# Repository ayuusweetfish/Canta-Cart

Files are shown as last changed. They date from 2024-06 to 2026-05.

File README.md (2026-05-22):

# Canta-Cart

Canta-Cart is a touch-operated musical instrument/synthesiser that takes the dimensions of a standard ID-1 card (85.6 × 53.98 mm). A portable little tune-maker in the pocket, it is easy for anyone to get hands on, yet versatile enough for the more aspiring of minds. It is plug-and-play — a USB-C power supply will take its sounds anywhere.

Additionally, the total BOM cost of CN¥5 / US$0.7 makes it an ideal greeting giveaway.

🎥 Videos:
- ["Merry Go Round of Life"](https://vimeo.com/989413177)
- ["A Short Hike"](https://vimeo.com/980840986)
- ["Pigeons and a Boy"](https://vimeo.com/970898009)

🕹️ [**Try in the browser**](https://ayuusweetfish.github.io/Canta-Cart/synth/)  
🌟 [Personal wiki page](https://ayu.land/canta)  
⚙️ [Hackaday project page](https://hackaday.io/project/196643-canta-cart)

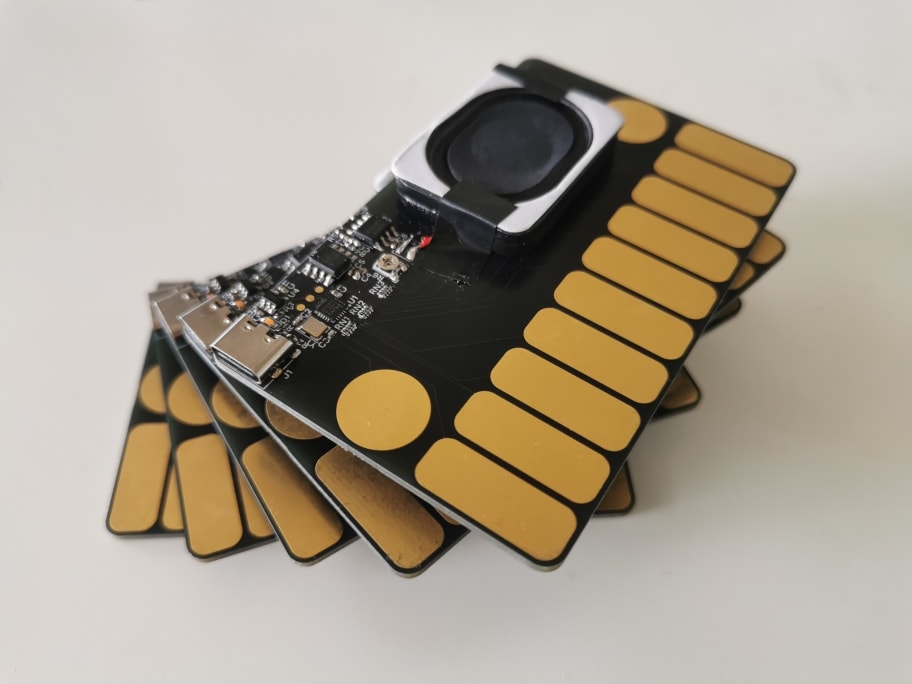
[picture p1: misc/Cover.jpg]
A stack of card-sized electronic devices


## Directory Structure
- **hw/**: Circuit board design in KiCad
- **fw/**: Firmware
  - To build this, you would need a copy of the following files:
    - **debug/Puya.PY32F0xx_DFP.1.2.1.pack**: Support pack used by PyOCD for flashing and debugging. Download from [Arm Keil’s website](https://www.keil.arm.com/packs/py32f0xx_dfp-puya/versions/). (SHA-1: `d3d40536eb2b465c1fbe483f0e1d66b776cbcbb6`)
      - This can also be installed through PyOCD’s pack management system.
    - **PY32F0xx_Firmware_V1.4.1/**: Firmware library. Download from [Puya’s website](https://www.puyasemi.com/en/gongjuyuruanjian.html). (Zip SHA-1: `c5146b8456401b8718d24bd71ab4e5568bd2c0f8`)
  - And the following software (versions for reference):
    - GNU Make (3.81)
    - Arm GNU Toolchain (GCC 10.3.1)
    - PyOCD (0.36.0)
  - Run `make` to build; `make flash` to upload. Add `OPT=-O3` for an optimised build (released version).
- **misc/synth/**: The synthesiser application (emulator) and its WebGL port, both implemented with [Sokol](https://github.com/floooh/sokol)
  - **canta_synth.h**: The actual synthesiser implementation, which is also included from the firmware
- **releases/**: Gerber files submitted to fabrication houses and firmware binaries at pinned revisions

## Licence
All content in this repository is distributed under CERN-OHL-S (CERN Open Hardware Licence Version 2, Strongly Reciprocal). See full text at `COPYING.txt` or [online](https://ohwr.org/cern_ohl_s_v2.txt).

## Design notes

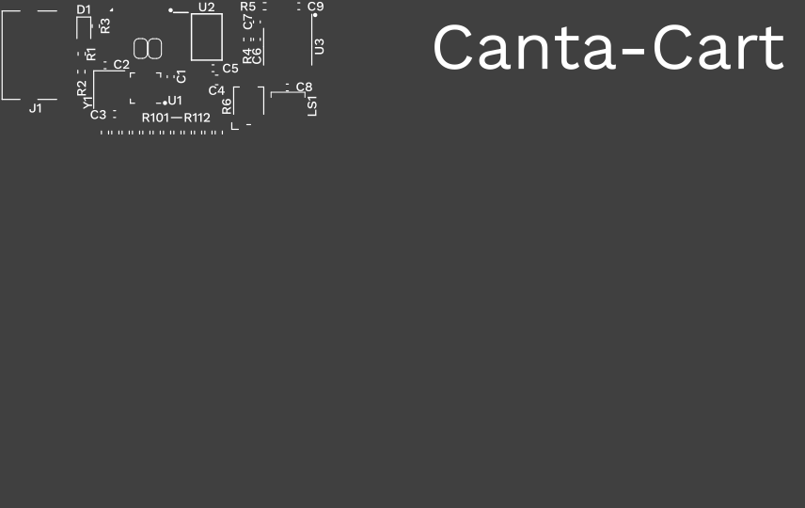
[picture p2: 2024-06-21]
misc/synth/silkscreen.png

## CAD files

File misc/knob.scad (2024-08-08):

$fa = 1.5;  // Facet min. angle (deg)
$fs = 0.05; // Facet min. length

// https://gist.github.com/mildsunrise/327a828e59ed97176ab7dbbaabb4d216
module gear(teeth, step, height=0.2) {
  angle = 360 / (teeth*2);
  radius = (step/2) / sin(angle/2);
  apothem = (step/2) / tan(angle/2);
  
  module circles() {
    for (i = [1:teeth])
      rotate(i*angle*2) translate([radius, 0, 0]) circle(step/2);
  }
  
  linear_extrude(height) difference() {
    union() {
      circle(apothem);
      circles();
    }
    rotate(angle) circles();
  }
}

// cylinder(h = 1.5, r = 3);
gear(24, 0.4, height = 1);

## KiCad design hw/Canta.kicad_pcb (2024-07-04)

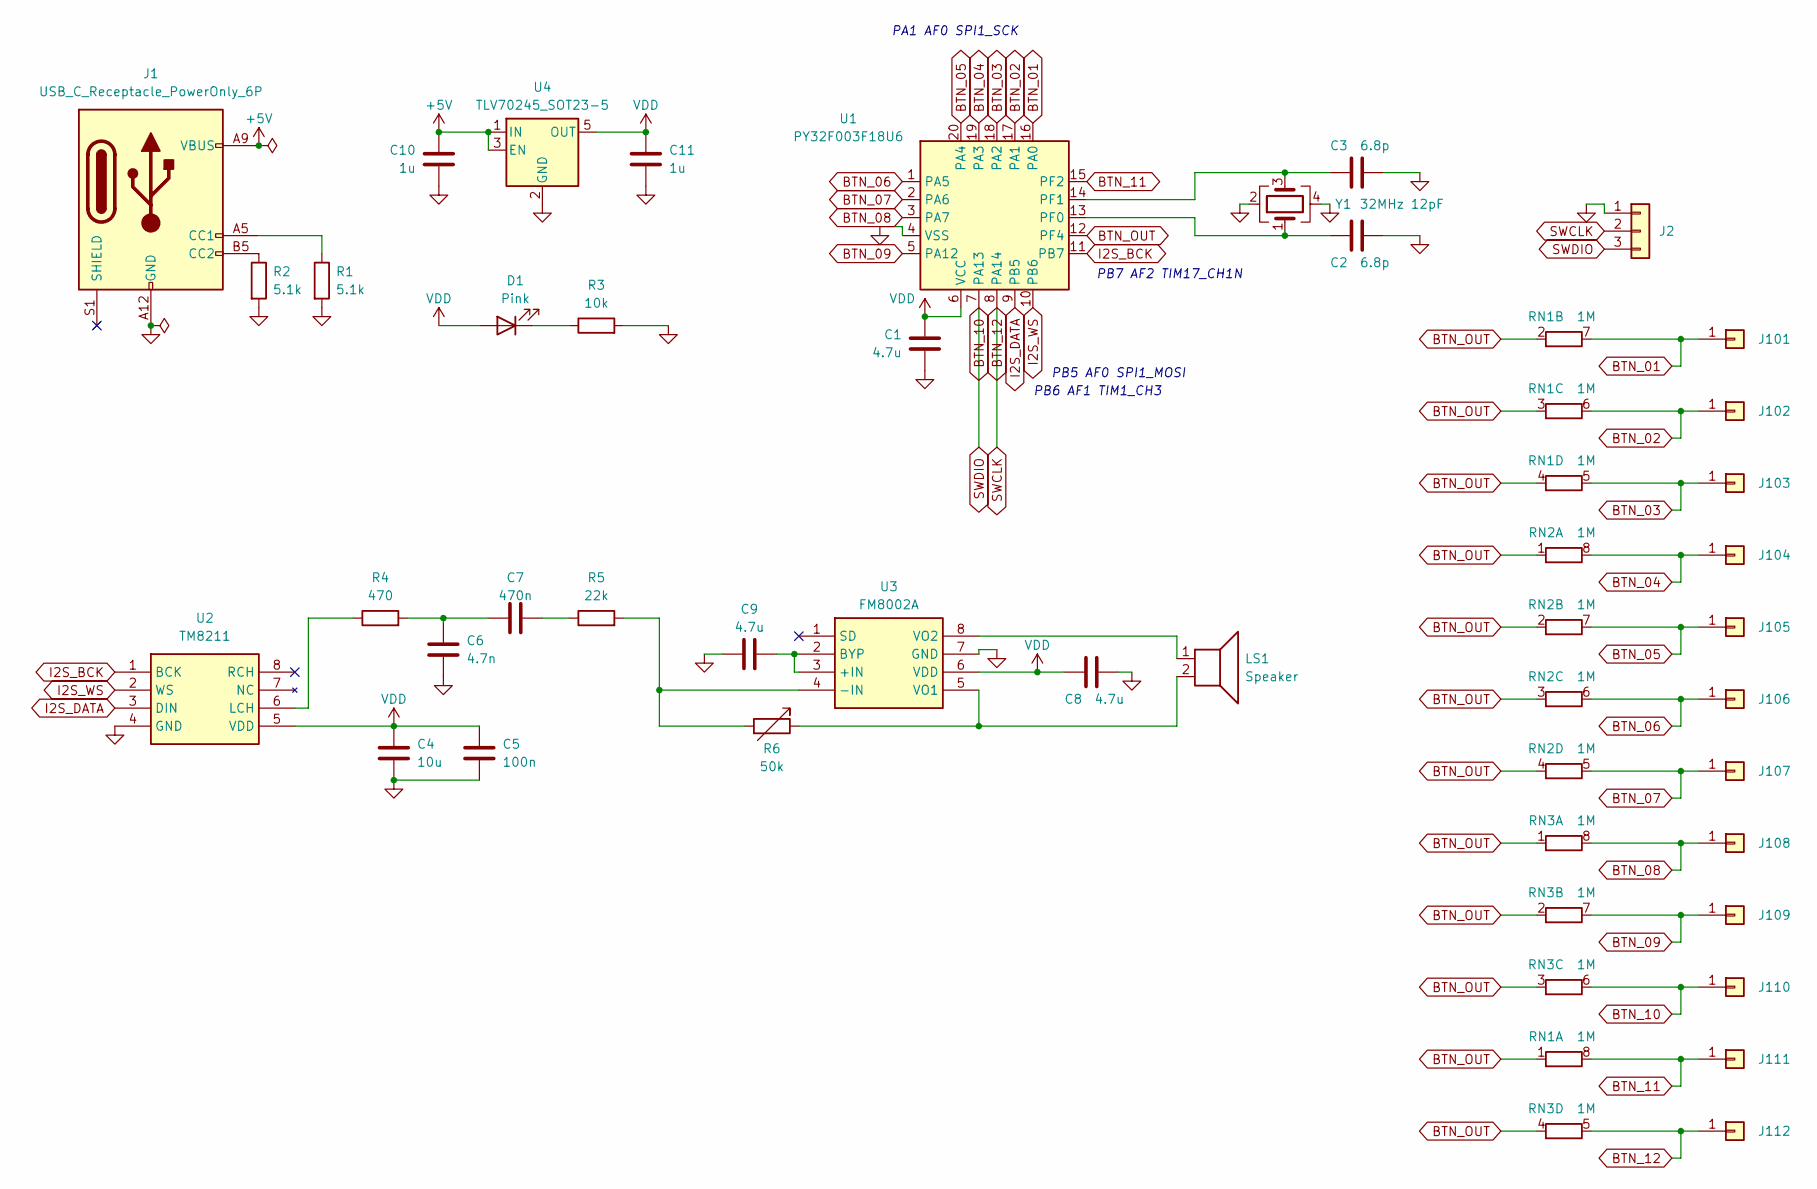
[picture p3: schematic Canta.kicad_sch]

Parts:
C1, C8, C9: 4.7u; C_0402_1005Metric
C2, C3: 6.8p; C_0402_1005Metric
C4: 10u; C_0603_1608Metric
C5: 100n; C_0402_1005Metric
C6: 4.7n; C_0402_1005Metric
C7: 470n; C_0402_1005Metric
C10, C11: 1u; C_0402_1005Metric
D1: Pink; LED_0603_1608Metric
J1: USB_C_Receptacle_PowerOnly_6P; USB_C_Receptacle
J2: Conn_01x03; TestPoints_1x03_P2.0
J101, J102, J103, J104, J105, J106, J107, J108, J109, J110: Conn_01x01; TouchPad_Keyboard
J111, J112: Conn_01x01; TouchPad_Transpose
LS1: Speaker; Speaker_1x02_P2
R1, R2: 5.1k; R_0402_1005Metric
R3: 10k; R_0402_1005Metric
R4: 470; R_0402_1005Metric
R5: 22k; R_0402_1005Metric
R6: 50k; Potentiometer_Bourns_TC33X_Vertical
RN1, RN2, RN3: 1M; R_Array_Convex_4x0402
U1: PY32F003F18U6; QFN-20-1EP_3x3mm_P0.4mm_EP1.65x1.65mm
U2: TM8211; SOIC127P600X196-8N; Manufacturer_Part_Number TM8211
U3: FM8002A; SOP-8_3.9x4.9mm_P1.27mm; Manufacturer_Part_Number MD8002A
U4: TLV70245_SOT23-5; SOT-23-5
Y1: 32MHz 12pF; Crystal_SMD_3225-4Pin_3.2x2.5mm

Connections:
+5V: C10.1, J1.A9 (VBUS), J1.B9 (VBUS), U4.1 (IN), U4.3 (EN)
BTN_01: J101.1, RN1.7 (R2.2), U1.16 (PA0)
BTN_02: J102.1, RN1.6 (R3.2), U1.17 (PA1)
BTN_03: J103.1, RN1.5 (R4.2), U1.18 (PA2)
BTN_04: J104.1, RN2.8 (R1.2), U1.19 (PA3)
BTN_05: J105.1, RN2.7 (R2.2), U1.20 (PA4)
BTN_06: J106.1, RN2.6 (R3.2), U1.1 (PA5)
BTN_07: J107.1, RN2.5 (R4.2), U1.2 (PA6)
BTN_08: J108.1, RN3.8 (R1.2), U1.3 (PA7)
BTN_09: J109.1, RN3.7 (R2.2), U1.5 (PA12)
BTN_10: J2.3, J110.1, RN3.6 (R3.2), U1.7 (PA13)
BTN_11: J111.1, RN1.8 (R1.2), U1.15 (PF2)
BTN_12: J2.2, J112.1, RN3.5 (R4.2), U1.8 (PA14)
BTN_OUT: RN1.1 (R1.1), RN1.2 (R2.1), RN1.3 (R3.1), RN1.4 (R4.1), RN2.1 (R1.1), RN2.2 (R2.1), RN2.3 (R3.1), RN2.4 (R4.1), RN3.1 (R1.1), RN3.2 (R2.1), RN3.3 (R3.1), RN3.4 (R4.1), U1.12 (PF4)
GND: C1.2, C2.2, C3.2, C4.2, C5.2, C6.2, C8.2, C9.1, C10.2, C11.2, J1.A12 (GND), J1.B12 (GND), J2.1, R1.2, R2.2, R3.2, U1.4 (VSS), U1.21 (PAD), U2.4 (GND), U3.7 (GND), U4.2 (GND), Y1.2, Y1.4
I2S_BCK: U1.11 (PB7), U2.1 (BCK)
I2S_DATA: U1.9 (PB5), U2.3 (DIN)
I2S_WS: U1.10 (PB6), U2.2 (WS)
unnamed: C6.1, C7.1, R4.2
unnamed: C7.2, R5.1
unnamed: D1.1 (K), R3.1
unnamed: J1.A5 (CC1), R1.1
unnamed: J1.B5 (CC2), R2.1
unnamed: C2.1, U1.13 (PF0), Y1.1
unnamed: C3.1, U1.14 (PF1), Y1.3
unnamed: R4.1, U2.6 (LCH)
unnamed: C9.2, U3.2 (BYP), U3.3 (+IN)
unnamed: R5.2, R6.2, U3.4 (-IN)
unnamed: LS1.2, R6.1, U3.5 (VO1)
unnamed: LS1.1, U3.8 (VO2)
VDD: C1.1, C4.1, C5.1, C8.1, C11.1, D1.2 (A), U1.6 (VCC), U2.5 (VDD), U3.6 (VDD), U4.5 (OUT)

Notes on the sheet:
PB5 AF0 SPI1_MOSI
PB7 AF2 TIM17_CH1N
PA1 AF0 SPI1_SCK
PB6 AF1 TIM1_CH3

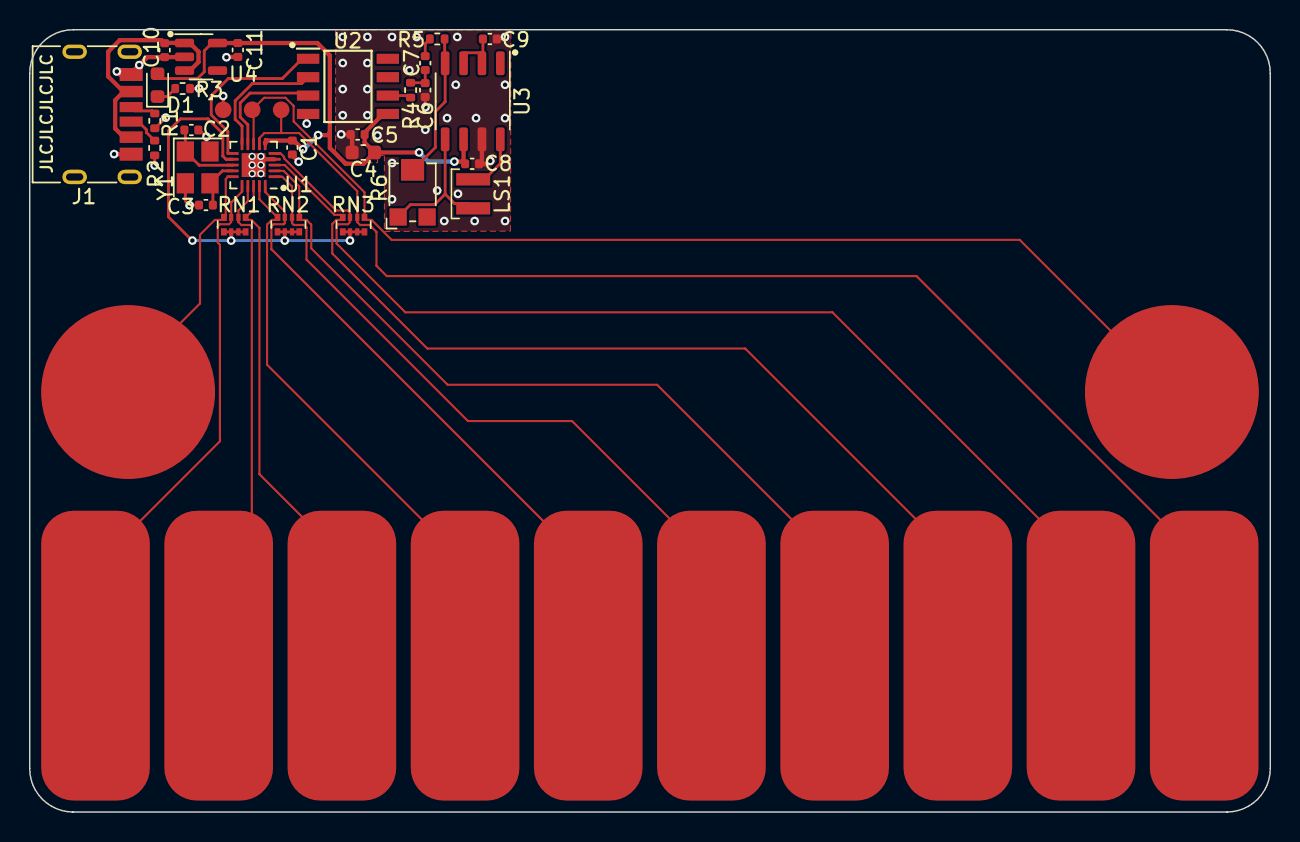
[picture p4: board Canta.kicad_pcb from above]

Board: 2 copper layers, 85.6 x 54.0 mm, 41 parts (0 on the bottom side), 31 nets.

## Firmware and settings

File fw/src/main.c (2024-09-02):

#include "py32f0xx_hal.h"
#include <assert.h>
#include <stdarg.h>
#include <stdbool.h>
#include <stdint.h>
#include <stdio.h>

#define SYNTH_SAMPLE_RATE 31250
#define SYNTH_EXTRA_SHIFT (-1)
#define SYNTH_STEREO
#include "../../misc/synth/canta_synth.h"

#define min(_a, _b) ((_a) < (_b) ? (_a) : (_b))
#define max(_a, _b) ((_a) > (_b) ? (_a) : (_b))

// To re-flash after a release build, pull PF4 (BTN_OUT) high before power-on
#define RELEASE
// #define PD_BTN_1     // Pull down button 1 to provide a ground probe clip
// #define INSPECT_ONLY // Output sensed values to debugger, disable sound output
// #define INSPECT      // Output sensed values to debugger

#define TOUCH_HARD_ON_THR  60
#define TOUCH_SOFT_ON_THR  30
#define TOUCH_OFF_THR      20

#define BTN_OUT_PORT GPIOF
#define BTN_OUT_PIN  GPIO_PIN_4

#ifndef RELEASE
static uint8_t swv_buf[64];
static size_t swv_buf_ptr = 0;
__attribute__ ((noinline, used))
void swv_trap_line()
{
  *(volatile char *)swv_buf;
}
static inline void swv_putchar(uint8_t c)
{
  if (c == '\n') {
    swv_buf[swv_buf_ptr >= sizeof swv_buf ?
      (sizeof swv_buf - 1) : swv_buf_ptr] = '\0';
    swv_trap_line();
    swv_buf_ptr = 0;
  } else if (++swv_buf_ptr <= sizeof swv_buf) {
    swv_buf[swv_buf_ptr - 1] = c;
  }
}
static void swv_printf(const char *restrict fmt, ...)
{
  static char s[32];
  va_list args;
  va_start(args, fmt);
  int r = vsnprintf(s, sizeof s, fmt, args);
  for (int i = 0; i < r && i < sizeof s - 1; i++) swv_putchar(s[i]);
  if (r >= sizeof s) {
    for (int i = 0; i < 3; i++) swv_putchar('.');
    swv_putchar('\n');
  }
}
#else
#define swv_printf(...)
#endif

SPI_HandleTypeDef spi1;
DMA_HandleTypeDef dma1_ch1;
TIM_HandleTypeDef tim1, tim17;

void dma_tx_half_cplt();
void dma_tx_cplt();

// Pull a set of pins to a given level and set them as input
static inline void pull_electrodes_port(GPIO_TypeDef *port, uint32_t pins, bool level)
{
  GPIO_InitTypeDef gpio_init = (GPIO_InitTypeDef){
    .Mode = GPIO_MODE_OUTPUT_PP,
    .Pin = pins,
    .Pull = GPIO_NOPULL,
    .Speed = GPIO_SPEED_FREQ_VERY_HIGH,
  };
  HAL_GPIO_Init(port, &gpio_init);
  HAL_GPIO_WritePin(port, pins, level);
  gpio_init.Mode = GPIO_MODE_INPUT;
  HAL_GPIO_Init(port, &gpio_init);
}

static inline void pull_electrodes(bool level)
{
  pull_electrodes_port(GPIOA,
  #ifndef PD_BTN_1
    GPIO_PIN_0 |
  #endif
    GPIO_PIN_1 | GPIO_PIN_2 | GPIO_PIN_3 | GPIO_PIN_4 |
    GPIO_PIN_5 | GPIO_PIN_6 | GPIO_PIN_7 | GPIO_PIN_12 |
  #ifdef RELEASE
    GPIO_PIN_13 | GPIO_PIN_14 |
  #endif
    0, level);

  pull_electrodes_port(GPIOF, GPIO_PIN_2, level);

#ifdef PD_BTN_1
  GPIO_InitTypeDef gpio_init = (GPIO_InitTypeDef){
    .Pin = GPIO_PIN_0,
    .Mode = GPIO_MODE_OUTPUT_PP,
    .Pull = GPIO_PULLDOWN,
    .Speed = GPIO_SPEED_FREQ_LOW,
  };
  HAL_GPIO_Init(GPIOA, &gpio_init);
  HAL_GPIO_WritePin(GPIOA, GPIO_PIN_0, 0);
#endif
}

#pragma GCC optimize("O3")
static inline void cap_sense()
{
  struct record_t {
    uint16_t t;
    uint16_t v;
  } record[16];

  uint16_t cap[12] = { 0 };
  uint16_t cap_sum[12] = { 0 };

  static const uint16_t MASK[12] = {
    1 <<  0,
    1 <<  1,
    1 <<  2,
    1 <<  3,
    1 <<  4,
    1 <<  5,
    1 <<  6,
    1 <<  7,
    1 << 12,
    1 << 13,
    1 <<  8,
    1 << 14,
  };
  static const uint16_t FULL_MASK =
    MASK[ 0] | MASK[ 1] | MASK[ 2] | MASK[ 3] | MASK[ 4] | MASK[ 5] |
    MASK[ 6] | MASK[ 7] | MASK[ 8] | MASK[ 9] | MASK[10] | MASK[11];

  inline void toggle(const bool level) {
    pull_electrodes(1 - level); // Pull to the opposite level before reading
    int n_records = 0;
    uint16_t last_v = (level == 1 ? ~FULL_MASK : FULL_MASK);
    record[n_records] = (struct record_t){.t = (uint16_t)-1, .v = last_v};
    __disable_irq();
    HAL_GPIO_WritePin(BTN_OUT_PORT, BTN_OUT_PIN, level);
    for (int i = 0; i < 100; i++) {
      uint32_t a = GPIOA->IDR;
      uint32_t f = GPIOF->IDR;
      uint16_t combined_v = a | (f << 6);
      uint16_t cur_v = (level == 1 ? (combined_v | last_v) : (combined_v & last_v));
      if (last_v != cur_v) n_records++;
      record[n_records] = (struct record_t){.t = i, .v = cur_v};
      last_v = cur_v;
    }
    __enable_irq();
    for (int j = 0; j < 12; j++) cap[j] = 0xffff;
    for (int i = 1; i <= n_records; i++) {
      uint16_t t = record[i - 1].t + 1;
      uint16_t diff = record[i - 1].v ^ record[i].v;
      for (int j = 0; j < 12; j++)
        if (diff & MASK[j]) cap[j] = t;
    }
    for (int j = 0; j < 12; j++)
      if (cap_sum[j] == 0xffff || cap[j] == 0xffff) cap_sum[j] = 0xffff;
      else cap_sum[j] += cap[j];
  }
  for (int its = 0; its < 5; its++) {
    toggle(1);
    toggle(0);
  }

  // Maintain a base value for each of the buttons

  // The base value increases by 1 every 1000 iterations (a few seconds)
  static const uint32_t BASE_MULT = 1024;
  static uint32_t base[12] = { UINT32_MAX };
  if (base[0] == UINT32_MAX) {
    for (int j = 0; j < 12; j++) base[j] = cap_sum[j] * BASE_MULT;
  } else {
    for (int j = 0; j < 12; j++) {
      base[j] += 1;
      if (base[j] > cap_sum[j] * BASE_MULT)
        base[j] = cap_sum[j] * BASE_MULT;
    }
  }
  for (int j = 0; j < 12; j++) cap_sum[j] -= base[j] / BASE_MULT;

  // A button is considered turned-on, if its sensed value exceeds `TOUCH_HARD_ON_THR`
  // or exceeds the larger of the nearby buttons' by `TOUCH_SOFT_ON_THR`

  static bool btns[12] = { false };
  for (int j = 0; j < 12; j++) {
    if (!btns[j]) {
      if (cap_sum[j] > TOUCH_HARD_ON_THR) btns[j] = true;
      else if (j < 10 && cap_sum[j] > TOUCH_SOFT_ON_THR) {
        uint16_t nearby = 0;
        if (j > 0) nearby = cap_sum[j - 1];
        if (j < 9 && nearby < cap_sum[j + 1]) nearby = cap_sum[j + 1];
        if (cap_sum[j] > nearby + TOUCH_SOFT_ON_THR)
          btns[j] = true;
      }
    } else {
      if (cap_sum[j] < TOUCH_OFF_THR) btns[j] = false;
    }
  }

#ifndef RELEASE
  btns[9] = btns[11] = false;
#endif
#ifdef PD_BTN_1
  for (int i = 0; i < 12; i++) if (i != 7) btns[i] = false;
#endif
#if defined(INSPECT_ONLY) || defined(INSPECT)
  for (int j = 0; j < 12; j++) swv_printf("%3d%c", min(999, cap_sum[j]), j == 11 ? '\n' : ' ');
  #if defined(INSPECT_ONLY)
  for (int j = 0; j < 12; j++) btns[j] = false;
  #endif
#endif

  __disable_irq();
  synth_buttons(btns);
  __enable_irq();
  // for (int j = 0; j < 12; j++) swv_printf("%d%c", (int)btns[j], j == 11 ? '\n' : ' ');
}

uint16_t audio_buf[256] = { 0 };
#define AUDIO_BUF_HALF_SIZE ((sizeof audio_buf / sizeof audio_buf[0]) / 2)

int main(void)
{
  HAL_Init();

  // ======== Clocks ========
  RCC_OscInitTypeDef osc_init = { 0 };
  osc_init.OscillatorType = RCC_OSCILLATORTYPE_HSE;
  osc_init.HSEState = RCC_HSE_ON;
  osc_init.HSEFreq = RCC_HSE_16_32MHz;
  HAL_RCC_OscConfig(&osc_init);

  RCC_ClkInitTypeDef clk_init = { 0 };
  clk_init.ClockType =
    RCC_CLOCKTYPE_SYSCLK |
    RCC_CLOCKTYPE_HCLK |
    RCC_CLOCKTYPE_PCLK1;
  clk_init.SYSCLKSource = RCC_SYSCLKSOURCE_HSE; // 32 MHz
  clk_init.AHBCLKDivider = RCC_SYSCLK_DIV1;
  clk_init.APB1CLKDivider = RCC_HCLK_DIV1;
  HAL_RCC_ClockConfig(&clk_init, FLASH_LATENCY_1);

  HAL_NVIC_SetPriority(SysTick_IRQn, 0, 0);

  // ======== Option byte ========
  // FLASH->OPTR |= FLASH_OPTR_NRST_MODE;  // Cannot be modified after POR
  FLASH_OBProgramInitTypeDef ob_prog;
  HAL_FLASH_OBGetConfig(&ob_prog);
  if (!(ob_prog.USERConfig & FLASH_OPTR_NRST_MODE)) {
    ob_prog.USERConfig |= FLASH_OPTR_NRST_MODE;
    HAL_FLASH_Unlock();
    HAL_FLASH_OB_Unlock();
    HAL_FLASH_OBProgram(&ob_prog);
    HAL_FLASH_OB_Lock();
    HAL_FLASH_OB_Launch();  // System reset
  }

  __HAL_RCC_GPIOA_CLK_ENABLE();
  __HAL_RCC_GPIOB_CLK_ENABLE();
  __HAL_RCC_GPIOF_CLK_ENABLE();
  GPIO_InitTypeDef gpio_init;

  // ======== Capacitive touch sensing ========
  // BTN_OUT
  gpio_init = (GPIO_InitTypeDef){
    .Pin = BTN_OUT_PIN,
    .Mode = GPIO_MODE_OUTPUT_PP,
    .Pull = GPIO_NOPULL,
    .Speed = GPIO_SPEED_FREQ_VERY_HIGH,
  };
  HAL_GPIO_Init(BTN_OUT_PORT, &gpio_init);
  HAL_GPIO_WritePin(BTN_OUT_PORT, BTN_OUT_PIN, 0);

  // For the electrodes, refer to `pull_electrodes()`

  // ======== SPI ========
  // PB5 AF0 SPI1_MOSI
  gpio_init = (GPIO_InitTypeDef){
    .Mode = GPIO_MODE_AF_PP,
    .Pull = GPIO_NOPULL,
    .Speed = GPIO_SPEED_FREQ_VERY_HIGH,
    .Alternate = GPIO_AF0_SPI1,
  };
  // gpio_init.Pin = GPIO_PIN_1; HAL_GPIO_Init(GPIOA, &gpio_init);
  gpio_init.Pin = GPIO_PIN_5; HAL_GPIO_Init(GPIOB, &gpio_init);

  __HAL_RCC_SPI1_CLK_ENABLE();
  spi1 = (SPI_HandleTypeDef){
    .Instance = SPI1,
    .Init = {
      .Mode = SPI_MODE_MASTER,
      .Direction = SPI_DIRECTION_2LINES,
      .DataSize = SPI_DATASIZE_16BIT,
      .CLKPolarity = SPI_POLARITY_LOW,  // CPOL = 0
      .CLKPhase = SPI_PHASE_1EDGE,      // CPHA = 0
      .NSS = SPI_NSS_SOFT,
      .BaudRatePrescaler = SPI_BAUDRATEPRESCALER_32,
        // 1 MHz bitrate = 31.25 kHz @ 16b stereo
      .FirstBit = SPI_FIRSTBIT_MSB,
    },
  };
  HAL_SPI_Init(&spi1);

  // ======== DMA ========
  __HAL_RCC_DMA_CLK_ENABLE();
  dma1_ch1 = (DMA_HandleTypeDef){
    .Instance = DMA1_Channel1,
    .Init = {
      .Direction = DMA_MEMORY_TO_PERIPH,
      .PeriphInc = DMA_PINC_DISABLE,
      .MemInc = DMA_MINC_ENABLE,
      .PeriphDataAlignment = DMA_PDATAALIGN_HALFWORD,
      .MemDataAlignment = DMA_MDATAALIGN_HALFWORD,
      .Mode = DMA_CIRCULAR,
      .Priority = DMA_PRIORITY_MEDIUM,
    },
  };
  HAL_DMA_Init(&dma1_ch1);
  HAL_DMA_ChannelMap(&dma1_ch1, DMA_CHANNEL_MAP_SPI1_TX);
  __HAL_LINKDMA(&spi1, hdmatx, dma1_ch1);

  HAL_NVIC_SetPriority(DMA1_Channel1_IRQn, 15, 1);
  HAL_NVIC_EnableIRQ(DMA1_Channel1_IRQn);

  // ======== Timer ========
  // PB6 AF1 TIM1_CH3
  gpio_init = (GPIO_InitTypeDef){
    .Pin = GPIO_PIN_6,
    .Mode = GPIO_MODE_AF_PP,
    .Pull = GPIO_NOPULL,
    .Speed = GPIO_SPEED_FREQ_VERY_HIGH,
    .Alternate = GPIO_AF1_TIM1,
  };
  HAL_GPIO_Init(GPIOB, &gpio_init);

  __HAL_RCC_TIM1_CLK_ENABLE();
  tim1 = (TIM_HandleTypeDef){
    .Instance = TIM1,
    .Init = {
      .Prescaler = 31,  // Synchronise with SPI bit clock
      .CounterMode = TIM_COUNTERMODE_DOWN,
      .Period = 31,
      .ClockDivision = TIM_CLOCKDIVISION_DIV1,
    },
  };
  HAL_TIM_PWM_Init(&tim1);
  HAL_TIM_PWM_ConfigChannel(&tim1, &(TIM_OC_InitTypeDef){
    .OCMode = TIM_OCMODE_PWM1,
    .Pulse = 15,
    .OCPolarity = TIM_OCPOLARITY_HIGH,
    .OCNPolarity = TIM_OCNPOLARITY_HIGH,
    .OCFastMode = TIM_OCFAST_DISABLE,
    .OCIdleState = TIM_OCIDLESTATE_RESET,
    .OCNIdleState = TIM_OCNIDLESTATE_RESET,
  }, TIM_CHANNEL_3);
  __HAL_TIM_MOE_ENABLE(&tim1);
  // Enable timer PWM output
  TIM1->CCER |= TIM_CCER_CC3E;

  // PB7 AF2 TIM17_CH1N
  gpio_init = (GPIO_InitTypeDef){
    .Pin = GPIO_PIN_7,
    .Mode = GPIO_MODE_AF_PP,
    .Pull = GPIO_NOPULL,
    .Speed = GPIO_SPEED_FREQ_VERY_HIGH,
    .Alternate = GPIO_AF2_TIM17,
  };
  HAL_GPIO_Init(GPIOB, &gpio_init);

  __HAL_RCC_TIM17_CLK_ENABLE();
  tim17 = (TIM_HandleTypeDef){
    .Instance = TIM17,
    .Init = {
      .Prescaler = 0,
      .CounterMode = TIM_COUNTERMODE_DOWN,
      .Period = 31,
      .ClockDivision = TIM_CLOCKDIVISION_DIV1,
    },
  };
  HAL_TIM_PWM_Init(&tim17);
  HAL_TIM_PWM_ConfigChannel(&tim17, &(TIM_OC_InitTypeDef){
    .OCMode = TIM_OCMODE_PWM1,
    .Pulse = 15,
    .OCPolarity = TIM_OCPOLARITY_HIGH,
    .OCNPolarity = TIM_OCNPOLARITY_HIGH,
    .OCFastMode = TIM_OCFAST_DISABLE,
    .OCIdleState = TIM_OCIDLESTATE_RESET,
    .OCNIdleState = TIM_OCNIDLESTATE_RESET,
  }, TIM_CHANNEL_1);
  __HAL_TIM_MOE_ENABLE(&tim17);
  // Enable timer PWM output
  TIM17->CCER |= TIM_CCER_CC1NE;

  // Enable SPI and DMA channel
  dma1_ch1.XferHalfCpltCallback = dma_tx_half_cplt;
  dma1_ch1.XferCpltCallback = dma_tx_cplt;
  dma1_ch1.XferErrorCallback = NULL;
  dma1_ch1.XferAbortCallback = NULL;

  // NOTE: This is number of transfers that gets written to DMA_CNDTRx,
  // but reference manual says CNDTR (NDT) is number of bytes?
  // Is datasheet copied from STM32F103 but PY32 actually follows STM32G0x0?
  HAL_DMA_Start_IT(&dma1_ch1, (uint32_t)audio_buf, (uint32_t)&SPI1->DR,
    sizeof audio_buf / sizeof audio_buf[0]);

  // Enable SPI DMA transmit request
  SPI1->CR2 |= SPI_CR2_TXDMAEN;

  // Separate into a function so that distance to the literal pool does not get too large
  __attribute__((noinline))
  void synchronised_start() {
    uint32_t addr_scratch, val_scratch, opnd_scratch;
    __asm__ volatile (
      // TIM1->CR1 |= TIM_CR1_CEN;
      "ldr %[addr], =%[tim1_cr1]\n"
      "ldr %[val], [%[addr], #0]\n"
      "ldr %[opnd], =%[tim_cr1_cen]\n"
      "orr %[val], %[opnd]\n"
      "str %[val], [%[addr], #0]\n"
      // TIM1->CNT = <tim1_cnt_val>;
      "ldr %[addr], =%[tim1_cnt]\n"
      "ldr %[val], =%[tim1_cnt_val]\n"
      "str %[val], [%[addr], #0]\n"
      "nop\n"
      "nop\n"
      "nop\n"
      "nop\n"
      "nop\n"
      "nop\n"
      "nop\n"
      "nop\n"
      "nop\n"
      "nop\n"
      "nop\n"
      "nop\n"
      "nop\n"
      "nop\n"
      "nop\n"
      "nop\n"
      "nop\n"
      "nop\n"
      "nop\n"
      "nop\n"
      "nop\n"
      // TIM17->CR1 |= TIM_CR1_CEN;
      "ldr %[addr], =%[tim17_cr1]\n"
      "ldr %[val], [%[addr], #0]\n"
      "ldr %[opnd], =%[tim_cr1_cen]\n"
      "orr %[val], %[opnd]\n"
      "str %[val], [%[addr], #0]\n"
      // TIM17->CNT = <tim17_cnt_val>;
      "ldr %[addr], =%[tim17_cnt]\n"
      "ldr %[val], =%[tim17_cnt_val]\n"
      "str %[val], [%[addr], #0]\n"
      // SPI1->CR1 |= SPI_CR1_SPE;
      "ldr %[addr], =%[spi1_cr1]\n"
      "ldr %[val], [%[addr], #0]\n"
      "ldr %[opnd], =%[spi_cr1_spe]\n"
      "orr %[val], %[opnd]\n"
      "str %[val], [%[addr], #0]\n"
      : [addr] "=&l" (addr_scratch),
        [val] "=&l" (val_scratch),
        [opnd] "=&l" (opnd_scratch)
      : [tim1_cnt] "i" (&TIM1->CNT), [tim1_cnt_val] "i" (2),
        [tim1_cr1] "i" (&TIM1->CR1), [tim_cr1_cen] "i" (TIM_CR1_CEN),
        [tim17_cnt] "i" (&TIM17->CNT), [tim17_cnt_val] "i" (27),
        [tim17_cr1] "i" (&TIM17->CR1),
        [spi1_cr1] "i" (&SPI1->CR1), [spi_cr1_spe] "i" (SPI_CR1_SPE)
      : "memory"
    );
  }
  synchronised_start();

  uint32_t last_tick = HAL_GetTick();
  while (1) {
    uint32_t cur_tick;
    while ((cur_tick = HAL_GetTick()) - last_tick < 1)
      HAL_PWR_EnterSLEEPMode(PWR_SLEEPENTRY_WFI);
    last_tick = cur_tick;
    cap_sense();
    // swv_printf("%lu\n", HAL_GetTick() - cur_tick);
  }
}

void NMI_Handler() { while (1) { } }
void HardFault_Handler() { while (1) { } }
void SVC_Handler() { while (1) { } }
void PendSV_Handler() { while (1) { } }
void SysTick_Handler()
{
  HAL_IncTick();
}
void DMA1_Channel1_IRQHandler()
{
  HAL_DMA_IRQHandler(&dma1_ch1);
}

static inline void refill_buffer(uint16_t *buf)
{
  // for (int i = 0; i < AUDIO_BUF_HALF_SIZE; i++)
  //   buf[i] = (last_btn[0] && i % 128 < 64) ? 0x01 : 0;
  synth_audio((int16_t *)(buf + 1), AUDIO_BUF_HALF_SIZE - 1);
  // for (int i = 0; i < AUDIO_BUF_HALF_SIZE; i++) buf[i] = 0x1;
}
void dma_tx_half_cplt()
{
  refill_buffer(audio_buf);
}
void dma_tx_cplt()
{
  refill_buffer(audio_buf + AUDIO_BUF_HALF_SIZE);
}

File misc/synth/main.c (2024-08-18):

// gcc -O2 -std=c99 main.c

// On macOS:
// gcc -O2 -std=c99 -x objective-c main.c -framework AppKit -framework OpenGL -framework AudioToolbox

// During development:
// gcc -std=c99 -DONLY_LIBS_IMPL -x objective-c main.c -c -O2 -o libs.o
// gcc -std=c99 -DNO_LIBS_IMPL main.c libs.o -framework AppKit -framework OpenGL -framework AudioToolbox

// Emscripten (SDK version 2.0.0):
// emcc -O2 -std=c99 main.c -sFULL_ES3 -o web/canta-cart.js
// Touch-end event fix, ref. emscripten-core/emscripten#5012, SO /q/52265891
// perl -pi -w -e 's/(var et=e.touches;for\(var i=0;i<et.length;\+\+i\)\{var touch=et\[i\];touches\[touch.identifier\]=touch)\}/$1;touch.isChanged=0}/' web/canta-cart.js

// Clean:
// rm a.out libs.o web/canta-cart.{js,wasm}

// Generate image binary header file:
// xxd -i silkscreen.png > silkscreen.png.h

// ============ Libraries ============
// Define NO_LIBS_IMPL for a statically linked (rather than amalgamated) build
#ifndef NO_LIBS_IMPL
  #define SOKOL_IMPL
  #define STB_IMAGE_IMPLEMENTATION
#endif

#ifdef __EMSCRIPTEN__
  #define SOKOL_GLES3
#else
  #define SOKOL_GLCORE
#endif

#include "sokol_app.h"
#include "sokol_audio.h"
#include "sokol_gfx.h"
#include "sokol_glue.h"

// Workaround for minor incompatibility (ref. edubart/sokol_gp#32)
#define SG_BACKEND_GLCORE33 SG_BACKEND_GLCORE
#include "sokol_gp.h"

#define STBI_ONLY_PNG
#define STBI_NO_STDIO
#define STBI_NO_LINEAR
#include "stb_image.h"
// ===================================

#ifndef ONLY_LIBS_IMPL

#define SYNTH_SAMPLE_RATE 44100
#define SYNTH_EXTRA_SHIFT 1
#include "canta_synth.h"
#include "silkscreen.png.h"

#include <assert.h>
#include <math.h>
#include <stdbool.h>
#include <stdio.h>

#ifndef M_PI
#define M_PI 3.1415926535897932384
#endif

static float audio_rms = 0;

static void audio_cb(float *buffer, int num_frames, int num_channels)
{
  int16_t ibuf[4096];
  assert(num_frames <= sizeof ibuf / sizeof ibuf[0]);

  synth_audio(ibuf, num_frames);

  float energy = 0;
  for (int i = 0; i < num_frames; i++) {
    float sample = (float)ibuf[i] / 65536;
    for (int j = 0; j < num_channels; j++)
      buffer[i * num_channels + j] = sample;
    energy += sample * sample;
  }
  audio_rms = audio_rms * 0.5f + (energy / num_frames) * 0.5f;
}

static sg_image load_image(const uint8_t *content, int content_len)
{
  int w, h, n_ch;
  uint8_t *data = stbi_load_from_memory(content, content_len, &w, &h, &n_ch, 4);
  assert(data != NULL && n_ch == 4);
  sg_image_desc image_desc = (sg_image_desc){
    .width = w,
    .height = h,
    .data = {
      .subimage = {{{ .ptr = data, .size = (size_t)(w * h * 4) }}},
    },
  };
  sg_image img = sg_make_image(&image_desc);
  stbi_image_free(data);
  return img;
}

static sg_image img_silkscreen;

static void init()
{
  sg_setup(&(sg_desc){
    .environment = sglue_environment(),
  });
  assert(sg_isvalid);

  sgp_setup(&(sgp_desc){ 0 });
  assert(sgp_is_valid());

  saudio_setup(&(saudio_desc){
    .sample_rate = SYNTH_SAMPLE_RATE,
    .stream_cb = audio_cb,
    .buffer_frames = 1024,
  });
  assert(saudio_sample_rate() == SYNTH_SAMPLE_RATE);

  img_silkscreen = load_image(silkscreen_png, silkscreen_png_len);
}

static bool buttons[12] = { false };

struct pointer {
  uintptr_t id;
  float x, y;
};

static inline bool pt_in_btn(int i, float x, float y)
{
  if (i < 10) {
    float cx = 45.4 + 85 * i;
    float cy = 431.9;
    float w = 75;
    float h = 200;
    return x >= cx - w/2 && x <= cx + w/2 &&
           y >= cy - h/2 && y <= cy + h/2;
  } else {
    float cx = (i == 10 ? 67.9 : 788.1);
    float cy = 250;
    float r = 60;
    return (x - cx) * (x - cx) + (y - cy) * (y - cy) <= r * r;
  }
}
static inline void pts_event(const struct pointer *pts, int n_pts)
{
  for (int j = 0; j < 12; j++) {
    buttons[j] = false;
    for (int i = 0; i < n_pts; i++)
      if (pt_in_btn(j, pts[i].x, pts[i].y)) { buttons[j] = true; break; }
  }
  synth_buttons(buttons);
}

static inline void circle_line(float cx, float cy, float r)
{
  sgp_point p[49];
  int n = 48, ptr = 0;
  for (int i = 0; i < n; i++) {
    float th = (float)M_PI * 2 / n * i;
    float x = cx + r * cosf(th);
    float y = cy + r * sinf(th);
    p[ptr++] = (sgp_point){ .x = x, .y = y };
  }
  p[ptr++] = (sgp_point){ .x = cx + r, .y = cy };
  sgp_draw_lines_strip(p, ptr);
}

static inline void circle_fill(float cx, float cy, float r)
{
  sgp_point p[50];
  int n = 48, ptr = 0;
  for (int i = 0; i <= n / 2; i++) {
    float th = (float)M_PI * 2 / n * i;
    float dx = r * cosf(th);
    float dy = r * sinf(th);
    p[ptr++] = (sgp_point){ .x = cx + dx, .y = cy + dy };
    p[ptr++] = (sgp_point){ .x = cx - dx, .y = cy - dy };
  }
  sgp_draw_filled_triangles_strip(p, ptr);
}

static inline void circle_key(float cx, float cy, float r, bool fill)
{
  float a = (fill ? 1 : 0.2);
  sgp_set_color(0.12 + 0.88 * a, 0.12 + 0.86 * a, 0.12 + 0.855 * a, 1);
  circle_fill(cx, cy, r);
}

static inline void rrect_fill(float cx, float cy, float w, float h, float r)
{
  sgp_point p[54];
  int n = 48;
  for (int i = 0; i <= n / 4; i++) {
    float th = (float)M_PI * 2 / n * i;
    float dx = r * cosf(th);
    float dy = r * sinf(th);
    p[i * 2 + 0] = (sgp_point){ .x = cx + (w/2 - r + dx), .y = cy + (h/2 - r + dy) };
    p[i * 2 + 1] = (sgp_point){ .x = cx - (w/2 - r + dx), .y = cy - (h/2 - r + dy) };
    p[n + 3 - (i * 2 + 0)] = (sgp_point){ .x = cx + (w/2 - r + dx), .y = cy - (h/2 - r + dy) };
    p[n + 3 - (i * 2 + 1)] = (sgp_point){ .x = cx - (w/2 - r + dx), .y = cy + (h/2 - r + dy) };
  }
  p[n + 4] = p[1];
  p[n + 5] = p[0];
  sgp_draw_filled_triangles_strip(p, n + 6);
}

static inline void rrect_key(float cx, float cy, float w, float h, float r, bool fill)
{
  float a = (fill ? 1 : 0.2);
  sgp_set_color(0.12 + 0.88 * a, 0.12 + 0.86 * a, 0.12 + 0.855 * a, 1);
  rrect_fill(cx, cy, w, h, r);
}

static void frame()
{
  int w = sapp_width(), h = sapp_height();
  sgp_begin(w, h);
  sgp_viewport(0, 0, w, h);
  sgp_project(0, 856, 0, 540);
  sgp_set_color(0.12f, 0.12f, 0.12f, 1.0f);
  sgp_clear();

  // Silkscreen
  sgp_set_blend_mode(SGP_BLENDMODE_BLEND);
  sgp_set_color(1.0, 0.98, 0.975, 1);
  sgp_set_image(0, img_silkscreen);
  sgp_draw_filled_rect(0, 0, 856, 540);
  sgp_reset_image(0);
  sgp_reset_blend_mode();

  // -4.5 dB: 0.5
  // -1.5 dB: 1
  float a = log10f(audio_rms);
  a = (a + 7.5) / 6;
  if (a > 1) a = 1; else if (a < 0) a = 0;
  sgp_set_color(0.12 + 0.88 * a, 0.12 + 0.86 * a, 0.12 + 0.855 * a, 1);
  circle_fill(428, 207, 100);
  sgp_set_color(1, 0.98, 0.975, 1);
  circle_line(428, 207, 100);

  circle_key( 67.9, 250, 60, buttons[10]);
  circle_key(788.1, 250, 60, buttons[11]);
  for (int i = 0; i < 10; i++)
    rrect_key(45.4 + 85 * i, 431.9, 75, 200, 22.5, buttons[i]);

  sg_begin_pass(&(sg_pass){ .swapchain = sglue_swapchain() });
  sgp_flush();
  sgp_end();
  sg_end_pass();
  sg_commit();
}

static void cleanup()
{
  puts("cleanup");
  sgp_shutdown();
  sg_shutdown();
}
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

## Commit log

2024-06-18 🎉 Initial commit, prepare symbols and footprints
    [Canta.kicad_pcb, Canta.kicad_sch]
2024-06-19 Finish schematic
    [Canta.kicad_sch]
2024-06-19 Fix thermal pad connection in PY32 symbol
    [Canta.kicad_pcb, Canta.kicad_sch]
2024-06-19 Layout, I think
    [Canta.kicad_pcb, Canta.kicad_sch]
2024-06-19 Routing, I think
    [Canta.kicad_pcb, Canta.kicad_sch]
2024-06-19 Switch supplies of audio ICs to 5 V
    [Canta.kicad_pcb, Canta.kicad_sch]
2024-06-19 Modify entire circuit to run on 5 V
    [Canta.kicad_pcb, Canta.kicad_sch]
2024-06-20 Update silkscreen
    [Canta.kicad_pcb, Canta.kicad_sch]
2024-06-20 Add back-side image
    [Canta.kicad_pcb]
2024-06-20 Finalise and submit for fab (Rev. 1)
    [Canta.kicad_pcb]
2024-06-21 Display buttons
2024-06-21 🎶 Actually making melodies!
2024-06-21 Display silkscreen image
2024-06-22 Implement interaction with pointer devices
2024-06-22 Fix touch-end event glitches
    [main.c]
2024-06-22 ✨ Firmware?!
2024-06-24 Add missing 3D models
    [Canta.kicad_pcb]
2024-06-24 Remove paste on touch keys
    [Canta.kicad_pcb]
2024-06-25 🚧 Non-working audio
2024-06-26 🎶Melodies!
2024-06-26 🚧 Timing?
2024-06-26 🚧 Strip down SPI DMA
2024-06-26 Further strip down SPI/DMA driver subroutine
2024-06-26 Switch synthesiser to stereo with correct frequencies
    [main.c]
2024-06-27 Adapt touch sense threshold to different sense resistor values
2024-06-28 Fix timing issues altogether (hopefully)
    [main.c]
2024-06-28 Update component values with actual assembly
    [Canta.kicad_pcb, Canta.kicad_sch]
2024-06-28 Don't want to deal with timing issues further
    [main.c]
2024-07-04 Add test option to ignore shorted keys…
    [main.c]
2024-07-04 Revise hardware design
    [Canta.kicad_pcb, Canta.kicad_sch]
2024-07-04 Revise pin assignment; submit for fab (Rev. 2)
    [Canta.kicad_pcb, Canta.kicad_sch]
2024-07-10 🚧 Prepare firmware for Rev. 2 (unfinished)
2024-07-11 Fix touch sensing bitmasks
    [main.c]
2024-07-11 🚧 Bit clock?
2024-07-18 Improve signal timings
    [Canta.kicad_sch]
2024-07-18 Improve algorithm to eliminate false triggers & missed presses
    [main.c]
2024-07-24 🎉 Add documentation
2024-08-02 Refactor pin pulling subroutines
2024-08-08 Add knob model
    [knob.scad]
2024-09-26 Add footprint for the new potentiometer model
